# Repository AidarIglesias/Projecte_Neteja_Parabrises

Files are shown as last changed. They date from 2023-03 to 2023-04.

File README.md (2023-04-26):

# Projecte Eines De Disseny  
## Sistema de Neteja-Parabrises D'Un Automobil  
###### David Miravent, Biel Hornas, Aidar Iglesias  

### Objectiu  
Aquest projecte te com a objectiu dissenyar el l'entorn electronic que conforma el sistema de neteja-parabrises d'un automobil.  

El projecte estara dividit en 7 parts:  

1. Diagrama de blocs i components
2. Esquematic i simulacions
3. Placement i routing (layout v1)
4. Pre-entega (layout v2)
5. Entrega final (layout v3)
6. Muntatge i soldadura
7. Test PCB  

----  

### Caracteristiques i epecificacions  
El sistema de neteja-parabrises te com a caracteristica principal, com ja diu el seu nom, netejar la lluna del parabrises. Com que aquest sistema sera part d'un conjunt de ECUs (Electronic Control Unit) d'un automobil, hi ha un serie d'elements que tots ells tindran en comu:  

* Una etapa de regulacio de tensio (es fara servir [L78S05CV])
* Un microcontrolador (es fara servir un [PIC18F2580] de 28 pins) encarregat del control del nostre modul i de la comunicacio amb els altres
* Un bus de programacio i debug del microcontrolador
* Un bus [CAN] que permet la comunicacio sincrona amb els altres moduls
* Un bus [I2C] (o be [SPI]) per a la comunicacio sincrona interna del nostre modul
* Un bus de comunicacio [USART] que permet monitoritzar el sistema des d'un ordinador extern
* Una botonera per permetre la interaccio entre l'usuari i el modul

El sistema ha de complir les seguents **especificacions**:  

* Dos motors amb el seu final de carrera
* Dues bombes de liquid neteja-parabrises
* Sensor digital de pluja
* Calefactor del vidre

----  

### Funcionament  

El sistema al complet estara controlat per el microcontrolador. Per al moviment dels neteja parabrises, es faran servir dos motors, un per davant i un per darrere. Aquests motors estaran controlats per uns drivers, els quals subministren el corrent necessari per activar uns reles que faran girar els motors en un sentit o en l'altre. Quan l'usuari desitgi o quan el sensor de pluja detecti pluja, el microcontrolador enviara el senyal d'activacio dels motors. Tambe s'incloura un sistema de final de carrera, que indicara quan s'ha acabat el trajecte de la escombreta del neteja-parabrises i la fara canviar de sentit.  

El sistema tambe implementa dues bombes de liquid neteja-parabrises, cadascuna d'elles controlada per un driver i un rele. Aquestes s'activaran quan el conductor ho desitgi i funcionaran de la mateixa manera que el neteja-parabrises: mitjançant un motor.  

Hi haura un mode de neteja automatic, accionat per un sensor digital de pluja. Quan es detecti pluja. Aleshores, el neteja-parabrises es posara en funcionament.  

Hi ha quatre opcions a escollir:
* Activar motor neteja-parabrises davanter
* Activar motor neteja-parabrises darrere
* Automatic (El sensor de pluja activa els neteja-parabrises)  

Mes enlla d'aquests 3 modes de funcionament, si aixi ho desitja, l'usuari pot activar les bombes de liquid manualment. Addicionalment, pot fer que les escombretes fagin una sola passada, tambe amb activacio manual.  

----  

### Diagrama de Blocs  

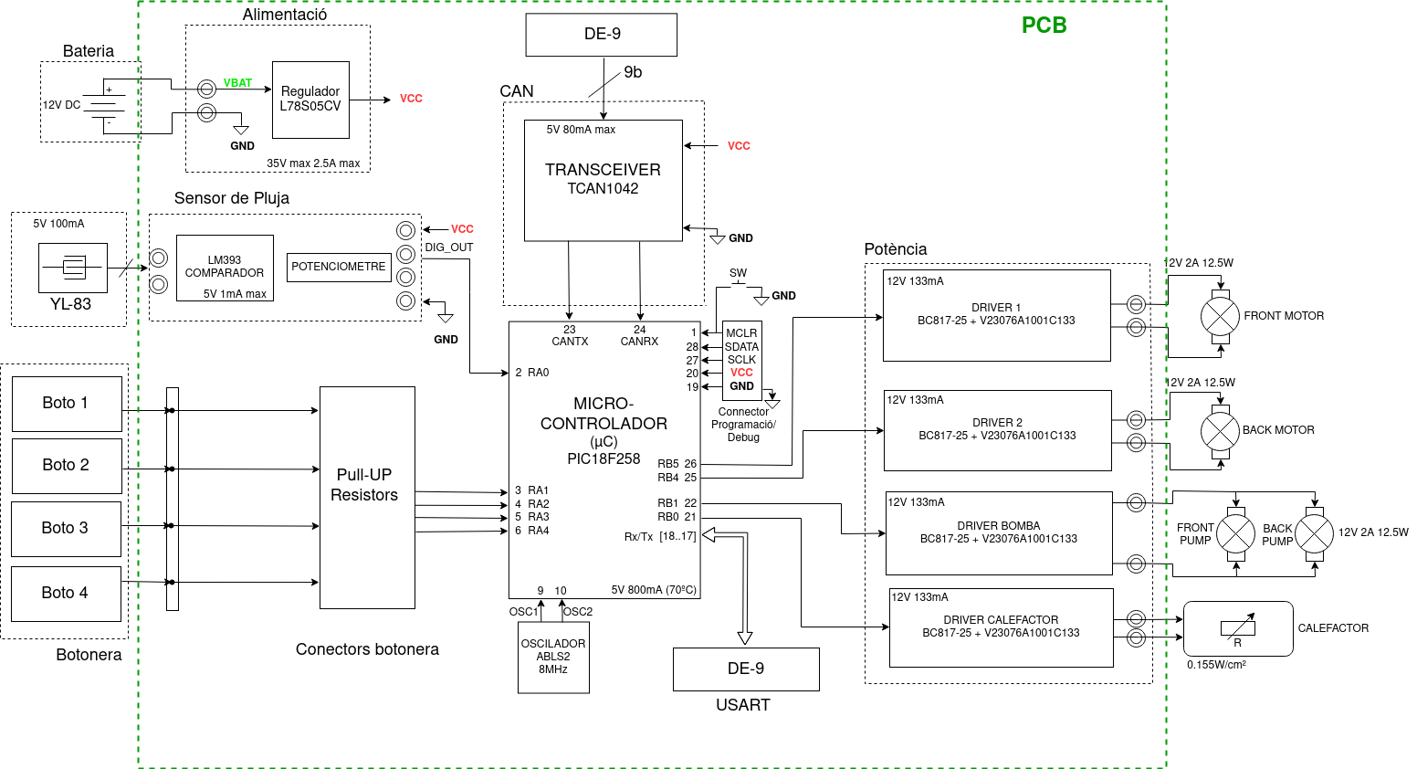
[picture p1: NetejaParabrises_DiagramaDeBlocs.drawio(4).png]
Diagrama 4
  
**Figura 3.** Versio 4 del diagrama de blocs - 13.04.2023.  

----  

### Taula de funcionament dels reles  

| **EnableM1** | **DriverM1** | **MOTOR 1** |  
| --- | --- | --- |
| 0 | 0 | 0 |  
| 0 | 1 | 0 |  
| 1 | 0 | 0 |  
| 1 | 1 | 1 |  

**Taula 1.** Taula del funcionament dels reles del motor neteja-parabrises davanter.  

| **EnableM2** | **DriverM2** | **MOTOR 2** |  
| --- | --- | --- |
| 0 | 0 | 0 |  
| 0 | 1 | 0 |  
| 1 | 0 | 0 |  
| 1 | 1 | 1 |  

**Taula 2.** Taula del funcionament dels reles del motor neteja-parabrises del darrere.

---  

### Components  

| Ref. | Descripcio | Datasheet |  
| ---- | --- | --- |
| PIC18F2580 | 28-Pin High Performance, Enhanced FLASH Microcontroller with CAN. S'encarrega del control integral del sistema. | [PIC18F2580] |  
| TCAN1042 | TCAN1042 Fault Protected CAN Transceiver with CAN FD. L'utilitzarem per a la comunicacio entre moduls independents. | [TCAN1042] |  
| LM1117-5.0 | 2A positive voltage regulator IC. Regulador LDO lineal de tres terminals, corrent nominal 2A i sortida a 5V. | [L78S05CV] |  
| ABLS2-8.000MHZ-D4Y-T | Low Profile Surface Mount Microprocessor Crystal. L'usarem com a font de senyal sincron de referencia per al microcontrolador. Es de 8MHz. | [ABLS2-8MHZ]  
| V23076A1001C133 | Automotive, PCB Single Power Relay K (Sealed) with wide voltage range and limiting continuous current 45A. Utilitzarem aquest rele per a les aplicacions de potencia, com ara la commutacio dels motors, de les bombes i del calefactor. | [V23076A1001C133]  
| BC817-25 | NPN general purpose transistor used for switching and amplification. Features high current (max. 500 mA) and low voltage (max. 45 V). Transistor bipolar NPN que farem servir per a amplificar el corrent de commutacio dels reles. | [BC817-25] |  
| YL-83 | Rain and snow are quickly and accurately detected with the YL-83 Rain Detector. L'implementarem de manera que quan detecti pluja, els neteja-parabrises s'accionin automaticament. | [YL-83] |  
| LM393 | Comparator with lower offset voltage, higher supply voltage capability, lower supply current, lower input bias current, lower propagation delay, and improved 2 kV ESD performance and input ruggedness through dedicated ESD clamps. Comparador que farem servir a l'hora de detectar si plou o no. | [LM393] |  
| 3362-¼” Square Trimpot | Trimming Potentiometer. Withstands harsh environments and immersion cleaning processes. Potenciometre que usarem per adjustar el llindar del sensor de pluja. | [3362-¼” Square Trimpot]  
| Flexible Heaters 78000 Series | Truly transparent, no wires in clear view area, optical grade, thin-film polyester, low power consumption for use with battery or line power. Tires conductores que tenen com a objectiu escalfar la lluna del darrere de l'automobil. | [Flexible Heaters 78000 Series] |  
| WLD4383 | Motor reductor _sinfin_ 12VDC, corrent nominal de 2A, velocitat nominal de 44rmp i una potencia de 12.5W. | [WLD4383]  
| EHDB9MF | Connector DB-9 de entrada-sortida de la comunicacio CAN. | [EHDB9MF] |  

----
### Historial de canvis  

| Data | Autor | Descripcio |  
| ---- | ----- | --- |
| 23.03.2023 | David Miravent | Tramesa de la tasca per a la primera versio de la presentacio. |  
| 27.03.2023 | Biel Hornas, David Miravent, Aidar Iglesias | Diagrama de blocs: Eliminat el sensor de temperatura. Eliminats els busos i transceivers CAN que estaven connectats entre els sensors + els que connectaven el PIC amb els motors. Modificada la botonera. Afegit el nou bus CAN. Modificat el connector de programacio i debug. Modificats els drivers i els components de potencia. Modificat l'oscil·lador. Afegit el driver del sensor de pluja. Afegits els consums individuals de cada component. Inclosos els pins de les connexions PIC-periferics. |  
| 28.03.2023 | Biel Hornas, David Miravent, Aidar Iglesias | Presentacio: Actualitzada la llista de components (diap. 5, 6). Inclosos els parametres d'interes per a cada component (diap. 8 - 18). Actualitzat el diagrama de blocs (diap. 19). |  
| 30.03.2023 | Biel Hornas, David Miravent | Realitzacio simulacions regulador de tensio + sensor de pluja, modificat el esquematic (sch) del projecte : s'han afegit totes les etapes del sistema en estructura de fulles jerarquiques. |  
| 31.03.2023 | Aidar Iglesias | README: actualitzada la imatge del diagrama de blocs. Corregit el valor de consum del PIC. Modificat el connector de la botonera |  
| 04.04.2023 | Biel Hornas | Actualitzada la jerarquia de fulls de l'esquematic: *Alimentacio*, *Digital*, *Analog* i *Potencia*. Sensor de pluja ficat tot en una mateixa capsa. Modificada la botonera: s'han eliminat els interruptors, ja que son externs a la placa. Corregits els noms de les *nets* a l'esquematic dels drivers de motors, que causaven curt-circuits. Canviat el model dels reles a V23086C1001A403, ja que te millor simbol i footprint. Modificat el connector d'alimentacio a l'esquematic del regulador. |  
| 05.04.2023 | David Miravent, Aidar Iglesias | Esquematic: Afegit titol al sheet *root*: **Sistema de Neteja-parabrises**. Modificada la ubicacio del LED d'alimentacio: del PIC al regulador. Reset Manual i Oscil·lador connectats directament al PIC. Corregides les connexions del connector DB-9 del bus CAN. Afegit connector DB-9 per al modul de comunicacio USART. Moduls de comunicacio CAN i USART connectats directament al PIC. |  
| 07.05.2023 | Aidar Iglesias | Esquematic: Canviat el regulador de tensio: LM1117-5 a L78S05CV (corrent de sortida major). Canviats els valors de les capacitats d'entrada i sortida del regulador. Corregides les connexions dels drivers de l'apartat de potencia (feien curt-circuit de la bateria a terra). Diagrama de blocs: actualitzat el regulador de tensio de LM1117 a L78S05CV. Corregits els valors de consum (PIC, LM393, TCAN1042) Presentacio: Actualitzat el diagrama de blocs. |  
| 10.04.2023 | David Miravent, Biel Hornas, Aidar Iglesias | Esquematic: Afegides les ferrites per separar el GND de potencia i el GND general. Layout: dissenyada la primera versio del Layout. |  
| 17.04.2023 | David Miravent, Biel Hornas, Aidar Iglesias | Esquematic: Canviat el node de VBAT al node despres del diode 1n4002 (protegit de canvis de polaritats). Corregida la separacio de GNDPWR i GND al regulador. Canviat el tipus de connector dels motors de pin-header a screwdriver. Canviat el divisor de tensio del sensor de pluja. |  
| 24.04.2023 | Biel Hornas, Aidar Iglesias, David Miravent | Esquematic: afegit el sistema de final de carrera. Assignades les xarxes dels BJTs a la classe ANG. Layout: Canviats totes les capacitats i totes les resistencies a SMD. Dissenyats els copper pours de manera que quedin regulars i uniformes per tota la PCB. Disminuit el tamany de les pistes de potencia. Recolocats alguns components. Re-routing general de la part de potencia. Afegides les llagrimes a les connexions pista-via i pista-pad.  
| 26.04.2023 | David Miravent, Biel Hornas, Aidar Iglesias | Generacio dels fitxers BOM i calcul del pressupost de la placa en tirada curta i llarga. Presentacio: Actualitzades les diapositives de l'esquematic i del layout. |  

[L78S05CV]:(https://www.google.com/url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)
[PIC18F2580]:(https://www.google.com/url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)
[CAN]:(https://www.google.com/url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)  
[I2C]:(https://www.google.com/url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)
[SPI]:(https://www.google.com/url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)
[USART]:(https://www.google.com/url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)
[TCAN1042]:(https://www.ti.com/lit/ds/symlink/tcan1042hv.pdf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)  
[ABLS2-8MHZ]:(https://www.mouser.es/datasheet/2/3/ABLS2-1775116.pdf)  
[V23076A1001C133]:(https://www.farnell.com/datasheets/2243264.pdf)  
[BC817-25]:(https://pdf1.alldatasheet.com/datasheet-pdf/view/16111/PHILIPS/BC817-25.html)  
[YL-83]:(https://urolakostapk.files.wordpress.com/2016/10yl-83-rain-detector-datasheet_low.pdf)  

[LM393]:(https://www.ti.com/lit/ds/symlink/lm393.pdf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)  
[3362-¼” Square Trimpot]:(https://www.farnell.com/datasheets/3171216.pdf)  
[Flexible Heaters 78000 Series]:(https://www.mouser.es/datasheet/2/187/honeywell-sensing-flexible-heaters-line-guide-0090-1525721.pdf)  
[WLD4383]:(https://transmotec.es/product/WLD4383-12-61/)  
[EHDB9MF]:(https://www.switchcraft.com/assets/1/24/EHDB9_EHHD15_SERIES_CD.PDF?4882)

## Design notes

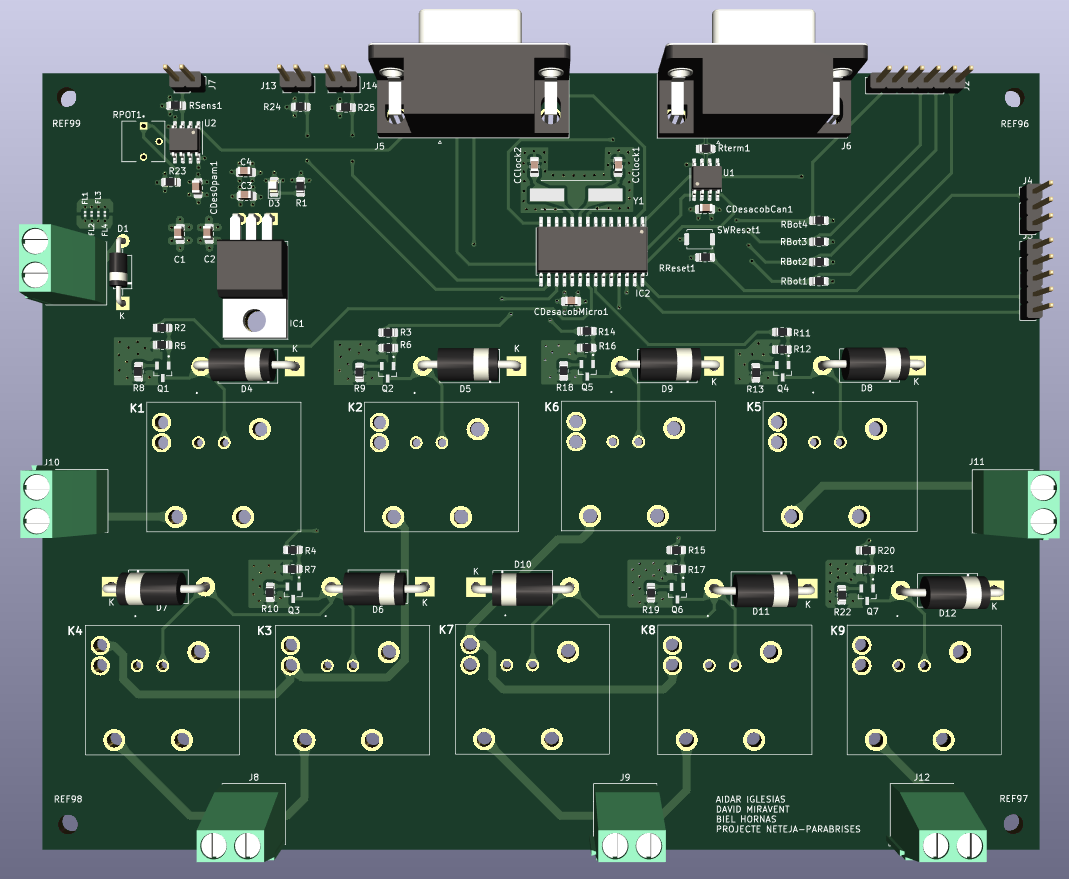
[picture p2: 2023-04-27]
Screenshot from 2023-04-27 13-25-02.png

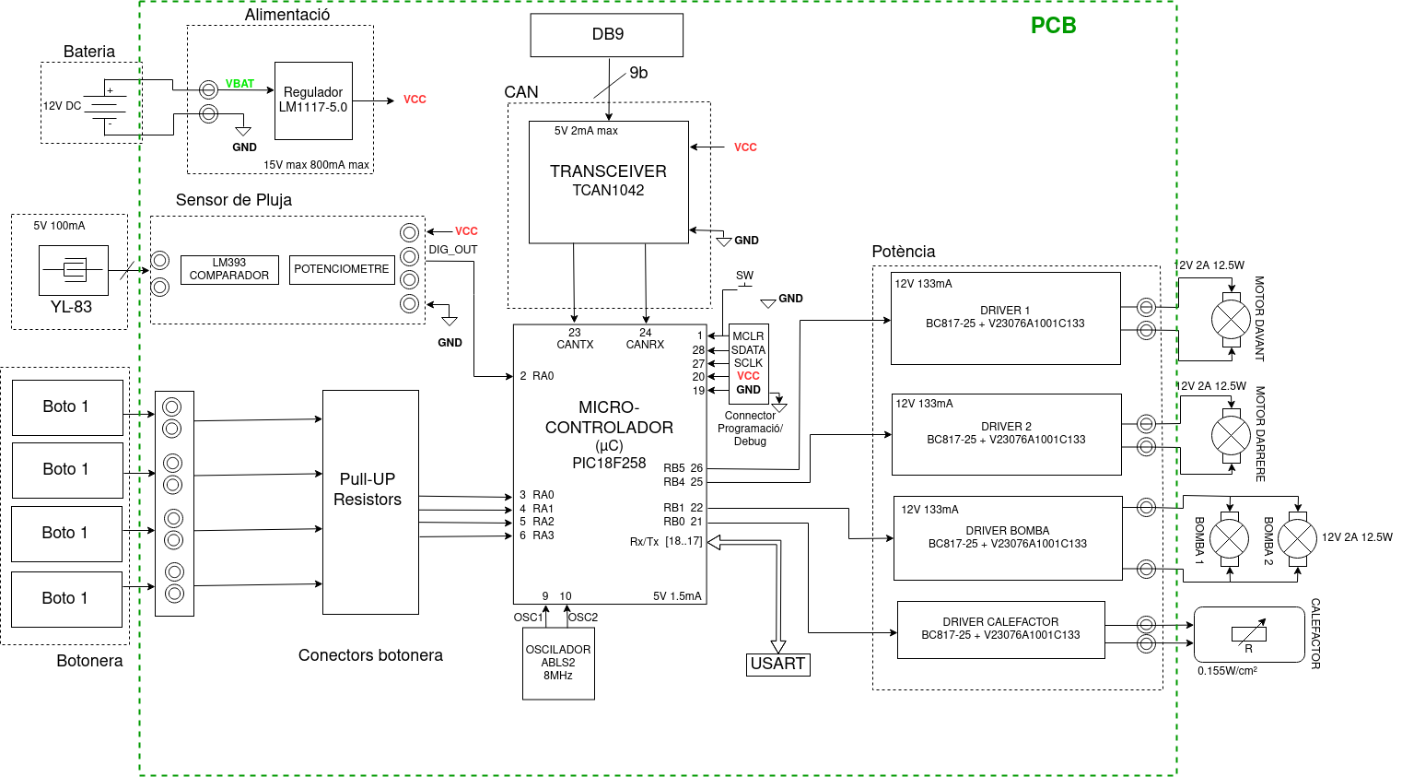
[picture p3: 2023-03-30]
NetejaParabrises_DiagramaDeBlocs.drawio.png

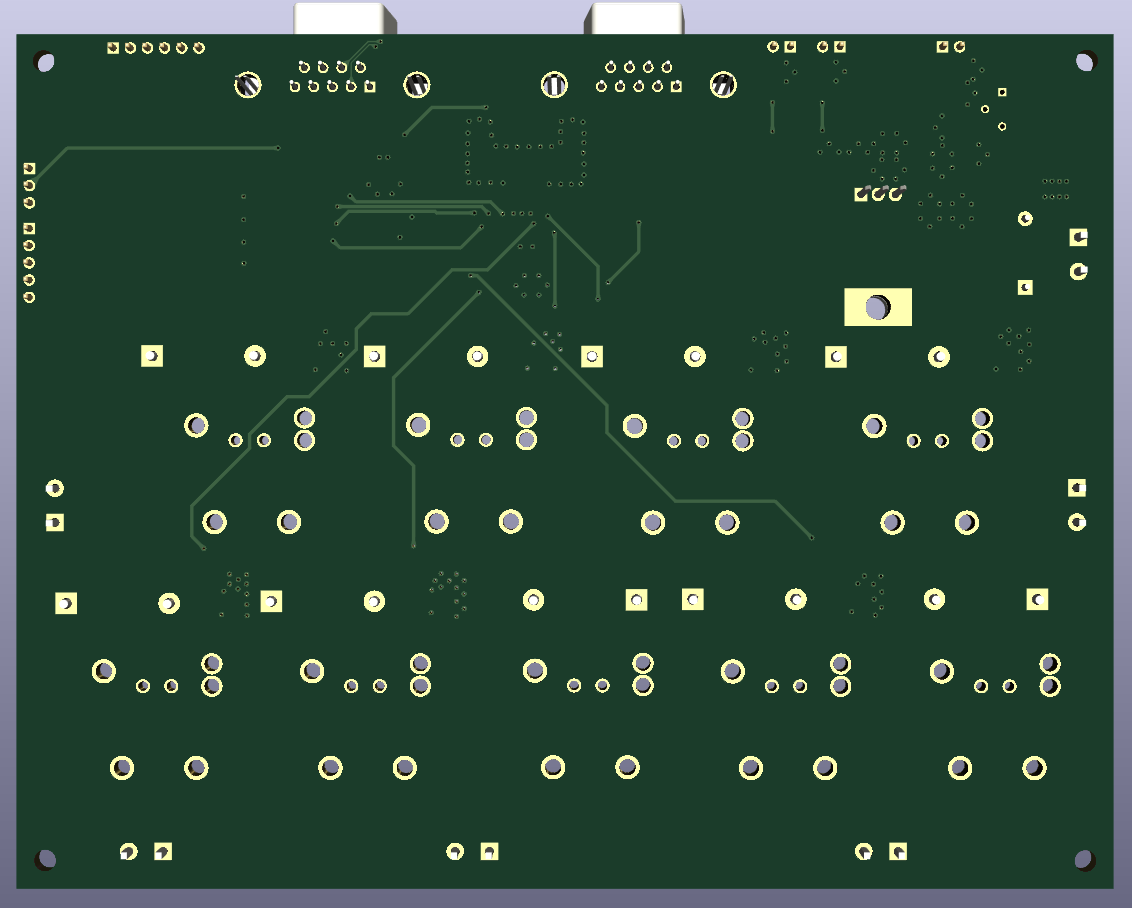
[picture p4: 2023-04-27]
Screenshot from 2023-04-27 13-25-26.png

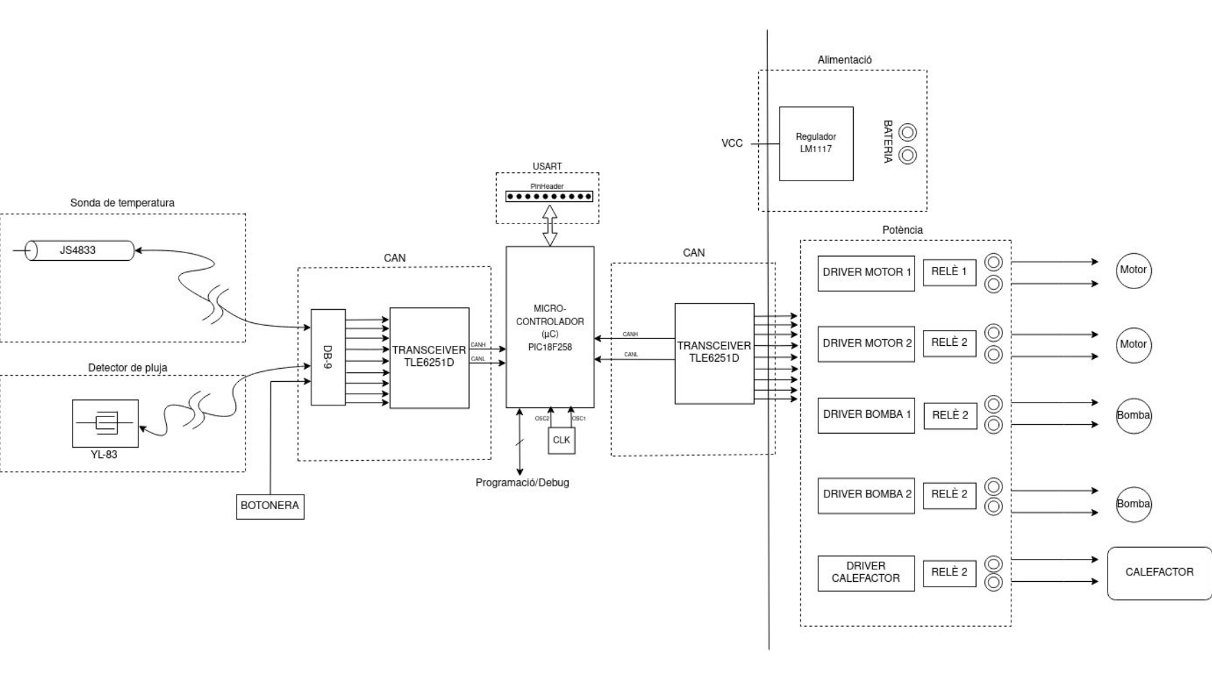
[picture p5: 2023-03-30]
diagrama-de-blocs-v1.png

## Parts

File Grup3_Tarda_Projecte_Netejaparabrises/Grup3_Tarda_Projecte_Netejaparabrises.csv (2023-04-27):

Reference | Value | Footprint | Datasheet | Arrow Part Number | Arrow Price/Stock | CURRENT | Comment | Description | EU_RoHS_Compliance | Height | MANUFACTURER | MAXIMUM_PACKAGE_HEIGHT | Manufacturer_Name | Manufacturer_Part_Number | Mouser Part Number | Mouser Price/Stock | PACKAGE | PARTNUMBER | PARTREV | REFDES | STANDARD | Sim.Device | Sim.Pins | TME | TYPE | VALUE | VIN-MAX | VIN-MIN | VOUT | Qty
C1, C4 | 100n | Capacitor_SMD:C_0805_2012Metric_Pad1.18x1.45mm_HandSolder | ~ |  |  |  |  |  |  |  |  |  |  |  |  |  |  |  |  |  |  |  |  |  |  |  |  |  |  | 2
C2 | 0.33u | Capacitor_SMD:C_0805_2012Metric_Pad1.18x1.45mm_HandSolder | ~ |  |  |  |  |  |  |  |  |  |  |  |  |  |  |  |  |  |  |  |  |  |  |  |  |  |  | 1
C3 | 0.1u | Capacitor_SMD:C_0805_2012Metric_Pad1.18x1.45mm_HandSolder | ~ |  |  |  |  |  |  |  |  |  |  |  |  |  |  |  |  |  |  |  |  |  |  |  |  |  |  | 1
CClock1, CClock2 | 22p | Capacitor_SMD:C_0805_2012Metric_Pad1.18x1.45mm_HandSolder | ~ |  |  |  |  |  |  |  |  |  |  |  |  |  |  |  |  |  |  |  |  |  |  |  |  |  |  | 2
CDesacobCan1 | 100n | Capacitor_SMD:C_0805_2012Metric_Pad1.18x1.45mm_HandSolder | ~ |  |  |  |  |  |  |  |  |  |  |  |  |  |  |  |  |  |  |  |  |  |  |  |  |  |  | 1
CDesacobMicro1 | 100n | Capacitor_SMD:C_0805_2012Metric_Pad1.18x1.45mm_HandSolder | ~ |  |  |  |  |  |  |  |  |  |  |  |  |  |  |  |  |  |  |  |  |  |  |  |  |  |  | 1
CDesOpam1 | 100n | Capacitor_SMD:C_0805_2012Metric_Pad1.18x1.45mm_HandSolder | ~ |  |  |  |  |  |  |  |  |  |  |  |  |  |  |  |  |  |  |  |  |  |  |  |  |  |  | 1
D1 | 1N4002 | Diode_THT:D_DO-41_SOD81_P10.16mm_Horizontal | http://www.vishay.com/docs/88503/1n4001.pdf |  |  |  |  |  |  |  |  |  |  |  |  |  |  |  |  |  |  |  |  |  |  |  |  |  |  | 1
D3 | LED | LED_SMD:LED_0805_2012Metric_Pad1.15x1.40mm_HandSolder | ~ |  |  |  |  |  |  |  |  |  |  |  |  |  |  |  |  |  |  |  |  |  |  |  |  |  |  | 1
D4-D12 | 1N5400 | Diode_THT:D_DO-201AD_P15.24mm_Horizontal | http://www.vishay.com/docs/88516/1n5400.pdf |  |  |  |  |  |  |  |  |  |  |  |  |  |  |  |  |  |  | D | 1=K 2=A |  |  |  |  |  |  | 9
FL1-FL4 | BLM03HD331SZ1D | BLM03HD331SZ1D:BEADC0603X33N |  |  |  |  |  |  |  |  |  |  |  |  |  |  |  |  |  |  |  |  |  |  |  |  |  |  |  | 4
IC1 | L78S05CV | Libreia:TO-220-3_Horizontal_TabDown_mod |  |  |  | 2.0 A |  |  |  |  | St Microelectronics |  |  |  |  |  | TO-220 |  |  |  |  |  |  | L78S05CV |  |  | 35.0 V | 8.0 V | 5.0 V | 1
IC2 | PIC18F258-I_SO | Package_SO:SOIC-28W_7.5x17.9mm_P1.27mm | https://datasheet.datasheetarchive.com/originals/distributors/Datasheets-35/DSA-681538.pdf | PIC18F258-I/SO | https://www.arrow.com/en/products/pic18f258-iso/microchip-technology |  |  | Microcontroller,PIC18F258-I/SO 40MHz |  | 2.64 |  |  | Microchip | PIC18F258-I/SO | 579-PIC18F258-I/SO | https://www.mouser.co.uk/ProductDetail/Microchip-Technology-Atmel/PIC18F258-I-SO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 |  |  |  |  |  |  |  |  |  |  |  |  |  | 1
J1, J8-J12 | Screw_Terminal_01x02 | TerminalBlock_Phoenix:TerminalBlock_Phoenix_MKDS-1,5-2-5.08_1x02_P5.08mm_Horizontal | ~ |  |  |  |  |  |  |  |  |  |  |  |  |  |  |  |  |  |  |  |  |  |  |  |  |  |  | 6
J2 | BOTONERA | Connector_PinHeader_2.54mm:PinHeader_1x06_P2.54mm_Vertical | ~ |  |  |  |  |  |  |  |  |  |  |  |  |  |  |  |  |  |  |  |  |  |  |  |  |  |  | 1
J3 | PROGRAMMING CON | Connector_PinHeader_2.54mm:PinHeader_1x05_P2.54mm_Vertical | ~ |  |  |  |  |  |  |  |  |  |  |  |  |  |  |  |  |  |  |  |  |  |  |  |  |  |  | 1
J4 | JP1 | Connector_PinHeader_2.54mm:PinHeader_1x03_P2.54mm_Vertical | ~ |  |  |  |  |  |  |  |  |  |  |  |  |  |  |  |  |  |  |  |  |  |  |  |  |  |  | 1
J5, J6 | DE9_Plug_MountingHoles | Connector_Dsub:DSUB-9_Female_Horizontal_P2.77x2.84mm_EdgePinOffset4.94mm_Housed_MountingHolesOffset7.48mm | ~ |  |  |  |  |  |  |  |  |  |  |  |  |  |  |  |  |  |  |  |  |  |  |  |  |  |  | 2
J7 | CONEXIOSENSOR | Connector_PinHeader_2.54mm:PinHeader_1x02_P2.54mm_Vertical | ~ |  |  |  |  |  |  |  |  |  |  |  |  |  |  |  |  |  |  |  |  |  |  |  |  |  |  | 1
J13, J14 | FINAL DE CARRERA | Connector_PinHeader_2.54mm:PinHeader_1x02_P2.54mm_Vertical | ~ |  |  |  |  |  |  |  |  |  |  |  |  |  |  |  |  |  |  |  |  |  |  |  |  |  |  | 2
K1-K9 | 1393280-6 | V23076A1001C133:V23076A1001C133 |  |  |  |  | 1393280-6 |  | Compliant |  |  |  |  |  |  |  |  |  |  |  |  |  |  |  |  |  |  |  |  | 9
Q1-Q7 | BC817-25_RF | BC817-25_RF:SOT95P237X112-3N |  |  |  |  |  |  |  |  | Taiwan Semiconductor | 1.12mm |  |  |  |  |  |  | I2001 |  | IPC 7351B |  |  |  |  |  |  |  |  | 7
R1 | 220R | Resistor_SMD:R_0805_2012Metric_Pad1.20x1.40mm_HandSolder | ~ |  |  |  |  |  |  |  |  |  |  |  |  |  |  |  |  |  |  |  |  |  |  |  |  |  |  | 1
R2-R4, R11, R14, R15, R20 | 620.3R | Resistor_SMD:R_0805_2012Metric_Pad1.20x1.40mm_HandSolder | ~ |  |  |  |  |  |  |  |  |  |  |  |  |  |  |  |  |  |  |  |  |  |  |  |  |  |  | 7
R5-R7, R12, R16, R17, R21 | 319.6R | Resistor_SMD:R_0805_2012Metric_Pad1.20x1.40mm_HandSolder | ~ |  |  |  |  |  |  |  |  |  |  |  |  |  |  |  |  |  |  |  |  |  |  |  |  |  |  | 7
R8-R10, R13, R18, R19, R22 | 13.4R | Resistor_SMD:R_0805_2012Metric_Pad1.20x1.40mm_HandSolder | ~ |  |  |  |  |  |  |  |  |  |  |  |  |  |  |  |  |  |  |  |  |  |  |  |  |  |  | 7
R23 | 10k | Resistor_SMD:R_0805_2012Metric_Pad1.20x1.40mm_HandSolder | ~ |  |  |  |  |  |  |  |  |  |  |  |  |  |  |  |  |  |  |  |  |  |  |  |  |  |  | 1
R24, R25 | 22k | Resistor_SMD:R_0805_2012Metric_Pad1.20x1.40mm_HandSolder | ~ |  |  |  |  |  |  |  |  |  |  |  |  |  |  |  |  |  |  |  |  |  |  |  |  |  |  | 2
RBot1-RBot4 | 22k | Resistor_SMD:R_0805_2012Metric_Pad1.20x1.40mm_HandSolder | ~ |  |  |  |  |  |  |  |  |  |  |  |  |  |  |  |  |  |  |  |  |  |  |  |  |  |  | 4
RPOT1 | 10k | POTENCIOMETRE:TRIM_3362P-1-103 | ~ |  |  |  |  |  |  |  |  |  |  |  |  |  |  |  |  |  |  |  |  |  |  |  |  |  |  | 1
RReset1 | 4.7k | Resistor_SMD:R_0805_2012Metric_Pad1.20x1.40mm_HandSolder | ~ |  |  |  |  |  |  |  |  |  |  |  |  |  |  |  |  |  |  |  |  |  |  |  |  |  |  | 1
RSens1 | 1k | Resistor_SMD:R_0805_2012Metric_Pad1.20x1.40mm_HandSolder | ~ |  |  |  |  |  |  |  |  |  |  |  |  |  |  |  |  |  |  |  |  |  |  |  |  |  |  | 1
Rterm1 | 120R | Resistor_SMD:R_0805_2012Metric_Pad1.20x1.40mm_HandSolder | ~ |  |  |  |  |  |  |  |  |  |  |  |  |  |  |  |  |  |  |  |  |  |  |  |  |  |  | 1
SWReset1 | SW_Push | Button_Switch_SMD:SW_Push_SPST_NO_Alps_SKRK | ~ |  |  |  |  |  |  |  |  |  |  |  |  |  |  |  |  |  |  |  |  |  |  |  |  |  |  | 1
U1 | TCAN1042DRQ1 | Package_SO:SOIC-8_3.9x4.9mm_P1.27mm |  |  |  |  |  |  |  |  | Texas Instruments |  |  |  |  |  |  | TCAN1042DRQ1 |  | RefDes |  |  |  |  | TYPE | Value |  |  |  | 1
U2 | LM393 | Package_SO:SOIC-8_3.9x4.9mm_P1.27mm | http://www.ti.com/lit/ds/symlink/lm393.pdf |  |  |  |  |  |  |  |  |  |  |  |  |  |  |  |  |  |  |  |  |  |  |  |  |  |  | 1
Y1 | ABLS2-8.000MHZ-D4Y-T | XTAL_ABLS2-8:XTAL_ABLS2-8.000MHZ-D4Y-T |  |  |  |  |  |  |  |  | Abracon | 3.3 mm |  |  |  |  |  |  | 11.15.2016 |  | Manufacturer Recommendations |  |  |  |  |  |  |  |  | 1

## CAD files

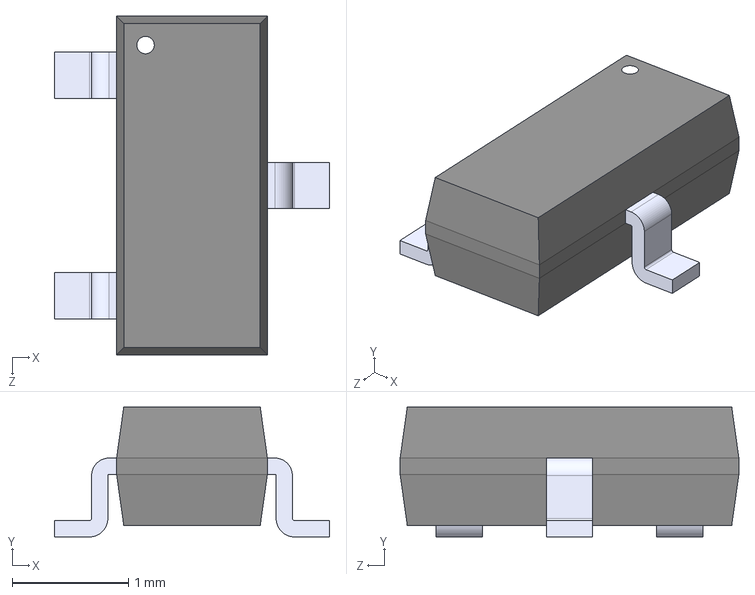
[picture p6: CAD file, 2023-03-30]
Llibreries/BJT/BC817-25_RF.step
2.37 x 1.12 x 2.92 mm

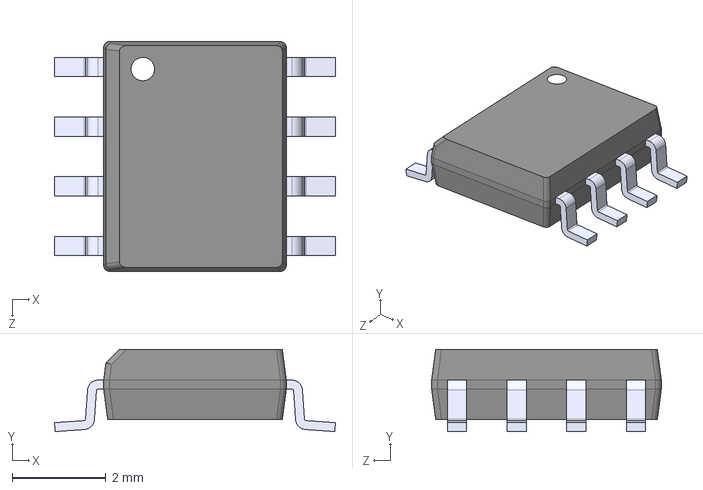
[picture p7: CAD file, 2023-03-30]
Llibreries/Comparador/LM393D.step
5.99 x 1.75 x 4.90 mm

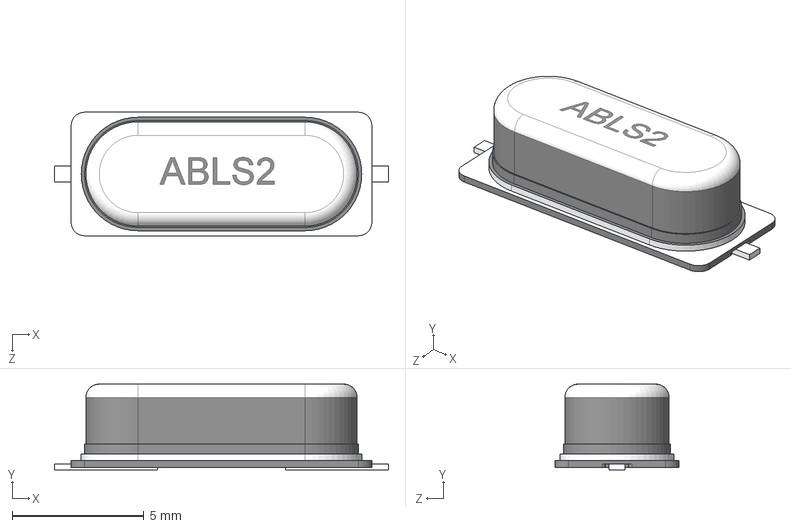
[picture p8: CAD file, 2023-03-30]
Llibreries/Cristall/ABLS2-8.000MHZ-D4Y-T.step
12.7 x 3.27 x 4.70 mm

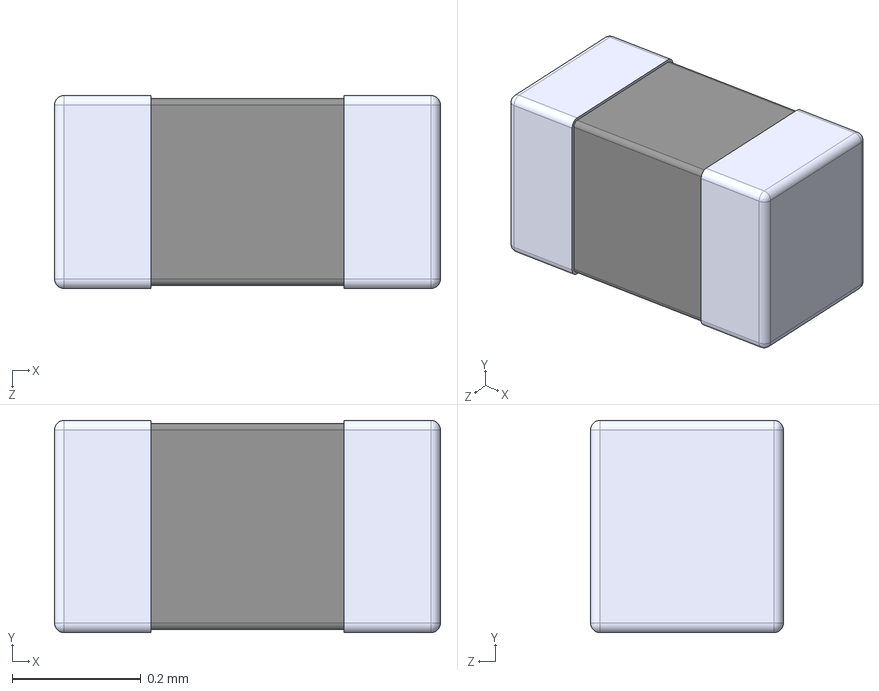
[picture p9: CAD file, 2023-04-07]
Llibreries/Ferritas/BLM03HD331SZ1D.step
0.6 x 0.33 x 0.3 mm

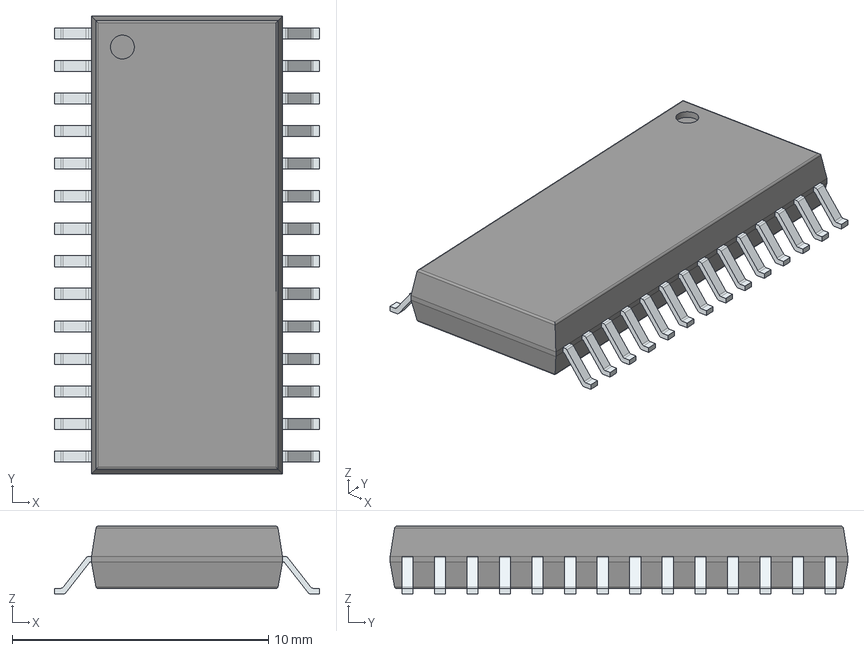
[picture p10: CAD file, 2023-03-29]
Llibreries/Micro/LIB_PIC18F258-I_SO/PIC18F258-I_SO/3D/PIC18F258-I_SO.stp
10.3 x 17.9 x 2.64 mm
PinsArrayLR

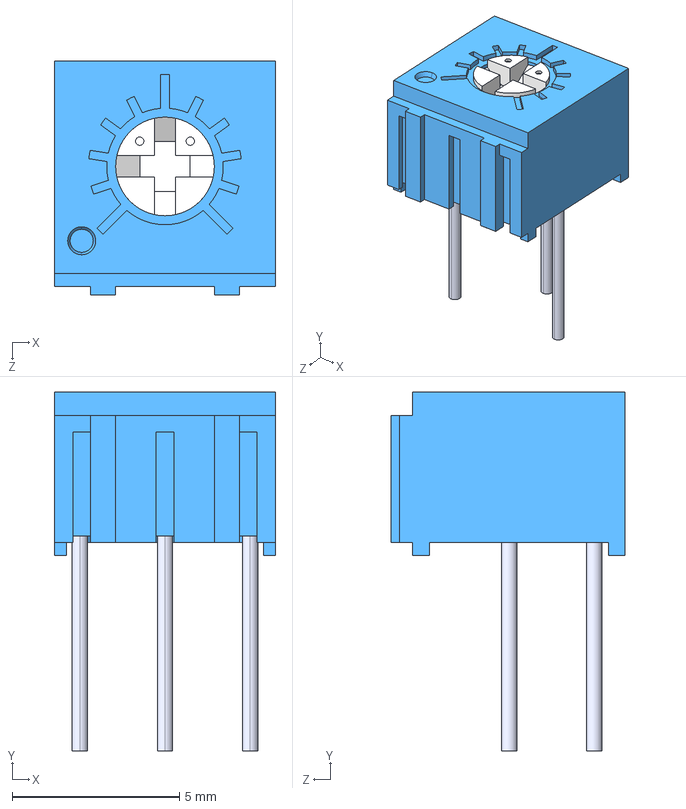
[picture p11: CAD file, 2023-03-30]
Llibreries/Potenciometre/3362P-1-103.step
6.60 x 10.7 x 6.99 mm

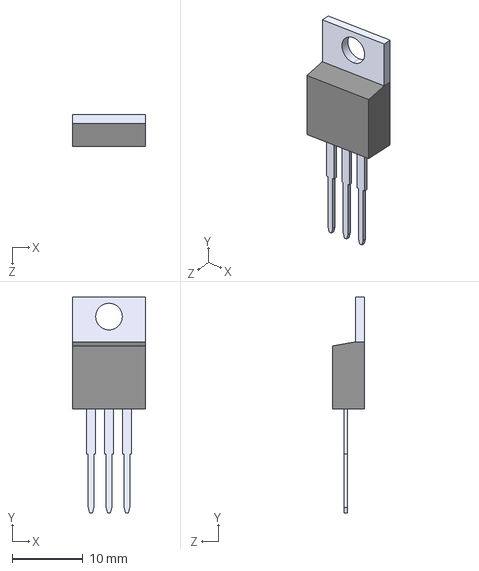
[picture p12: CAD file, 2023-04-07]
Llibreries/Regulador/L78S05CV.step
10.3 x 30.6 x 4.57 mm

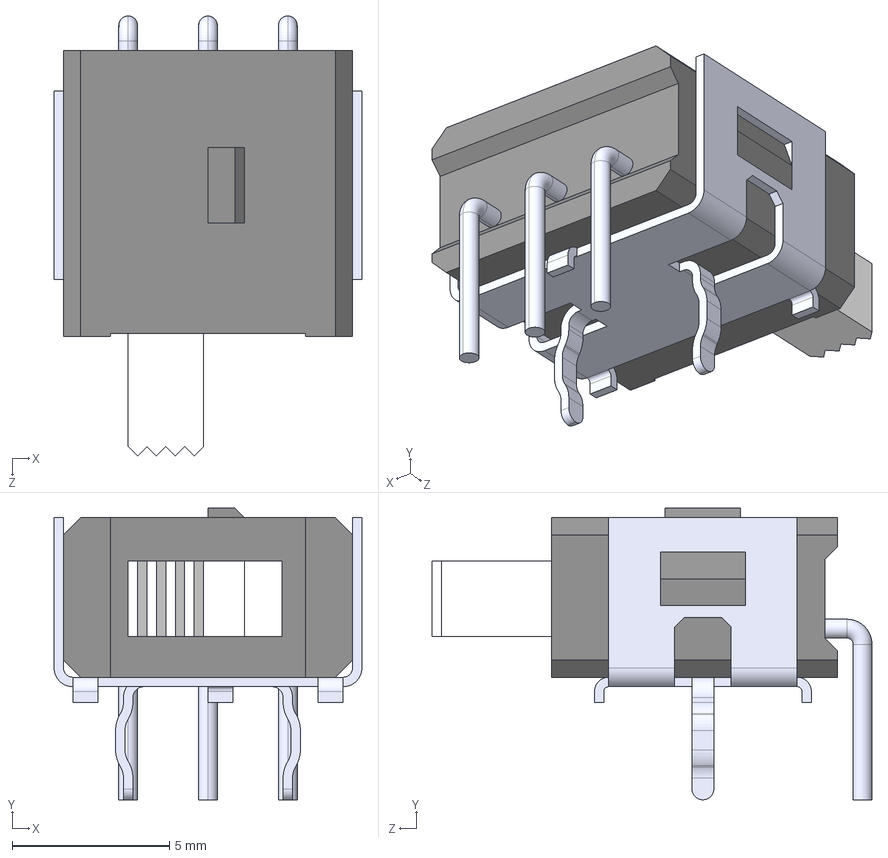
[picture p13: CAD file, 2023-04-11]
Llibreries/switch1x1/AS11CH/AS11CH.step
9.80 x 9.28 x 14.0 mm

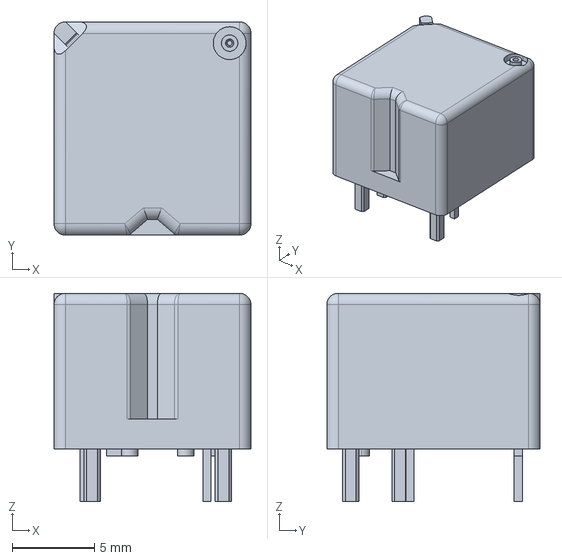
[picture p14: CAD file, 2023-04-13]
Llibreries/Rele/1393280-6/1393280-6.step
12.0 x 13.0 x 12.7 mm

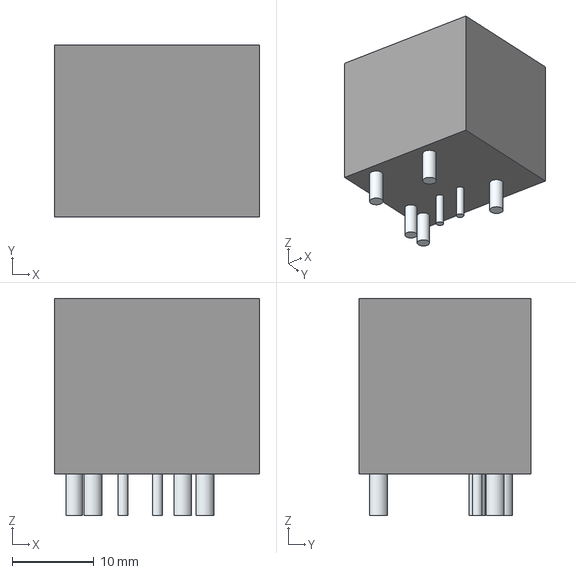
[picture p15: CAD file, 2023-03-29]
Llibreries/Rele/LIB_V23076A1001C133/V23076A1001C133/3D/V23076A1001C133.stp
25.1 x 21.1 x 26.6 mm
Leads x 7

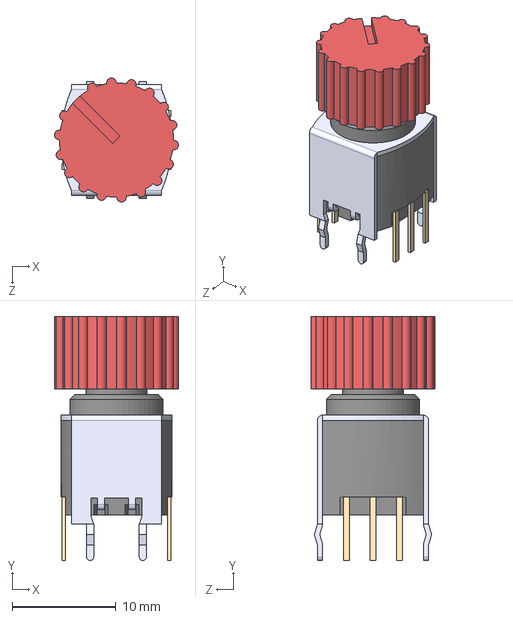
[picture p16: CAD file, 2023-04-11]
Llibreries/switch3x1/NR01103ANG13-1C/NR01103ANG13-1C.step
12.0 x 23.5 x 12.0 mm

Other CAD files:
Llibreries/Micro/LIB_PIC18F258-I_SO/PIC18F258-I_SO/Allegro/soic127p1034x264-28n.psm
Llibreries/Micro/LIB_PIC18F258-I_SO/PIC18F258-I_SO/DEHDL/pic18f258_i_so/chips/chips.prt
Llibreries/Rele/LIB_V23076A1001C133/V23076A1001C133/Allegro/v23076a1001c133.psm
Llibreries/Rele/LIB_V23076A1001C133/V23076A1001C133/DEHDL/v23076a1001c133/chips/chips.prt

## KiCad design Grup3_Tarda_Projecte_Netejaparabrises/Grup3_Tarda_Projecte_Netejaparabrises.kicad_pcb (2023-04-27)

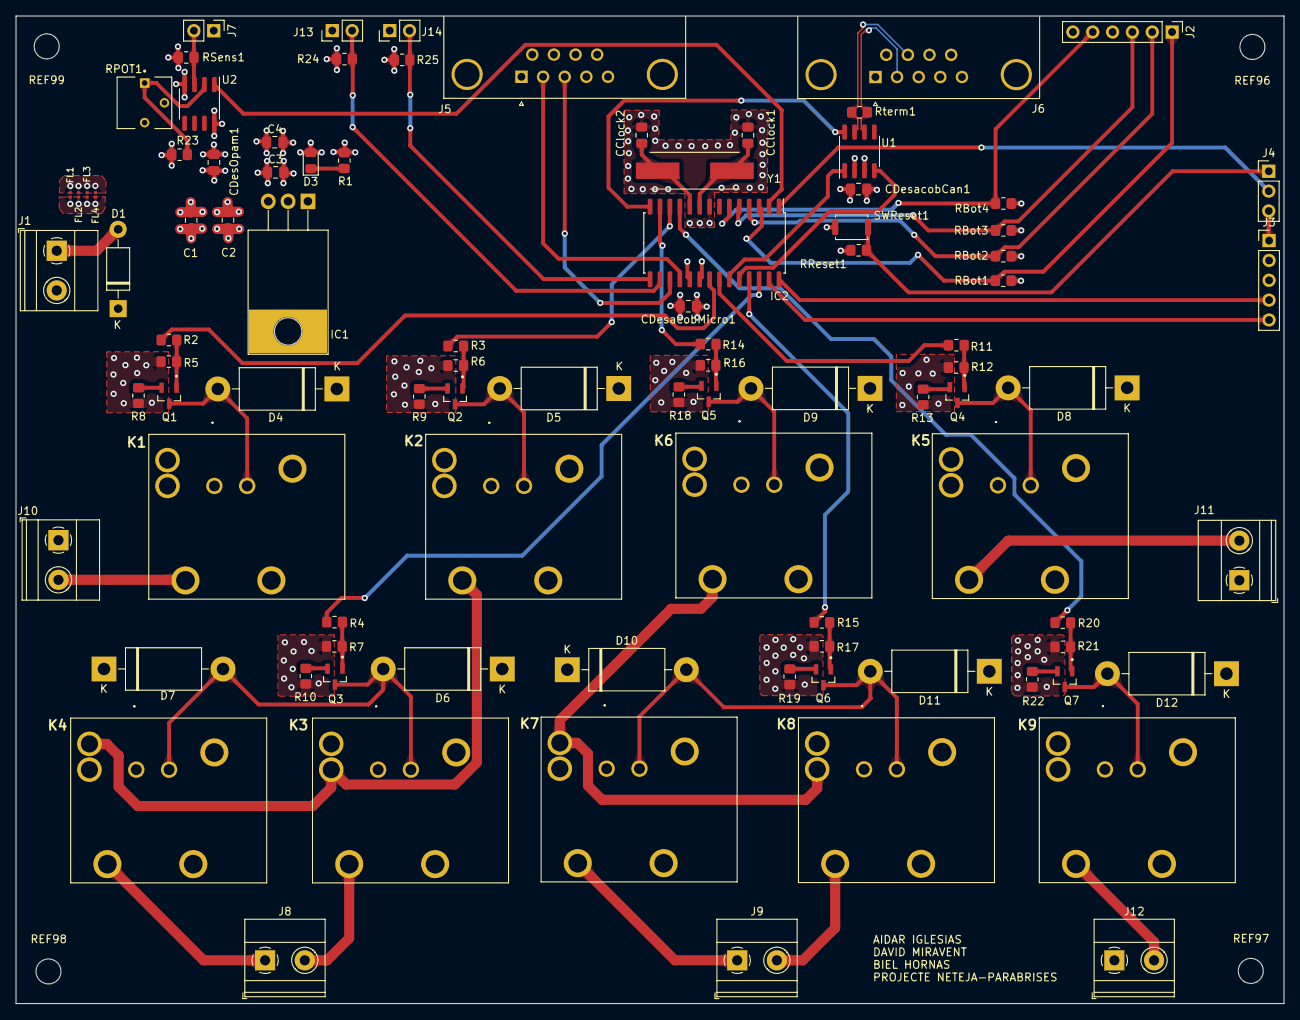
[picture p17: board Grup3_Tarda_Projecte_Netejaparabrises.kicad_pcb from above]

Board: 4 copper layers, 162.4 x 126.5 mm, 97 parts (0 on the bottom side), 66 nets.

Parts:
C1, C4: 100n; C_0805_2012Metric_Pad1.18x1.45mm_HandSolder
C2: 0.33u; C_0805_2012Metric_Pad1.18x1.45mm_HandSolder
C3: 0.1u; C_0805_2012Metric_Pad1.18x1.45mm_HandSolder
CClock1, CClock2: 22p; C_0805_2012Metric_Pad1.18x1.45mm_HandSolder
CDesOpam1: 100n; C_0805_2012Metric_Pad1.18x1.45mm_HandSolder
CDesacobCan1: 100n; C_0805_2012Metric_Pad1.18x1.45mm_HandSolder
CDesacobMicro1: 100n; C_0805_2012Metric_Pad1.18x1.45mm_HandSolder
D1: 1N4002; D_DO-41_SOD81_P10.16mm_Horizontal
D3: LED; LED_0805_2012Metric_Pad1.15x1.40mm_HandSolder
D4, D5, D6, D7, D8, D9, D10, D11, D12: 1N5400; D_DO-201AD_P15.24mm_Horizontal
FL1, FL2, FL3, FL4: BLM03HD331SZ1D; BEADC0603X33N
IC1: L78S05CV; TO-220-3_Horizontal_TabDown_mod
IC2: PIC18F258-I_SO; SOIC-28W_7.5x17.9mm_P1.27mm
J1, J8, J9, J10, J11, J12: Screw_Terminal_01x02; TerminalBlock_Phoenix_MKDS-1,5-2-5.08_1x02_P5.08mm_Horizont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
J2: BOTONERA; PinHeader_1x06_P2.54mm_Vertical
J3: PROGRAMMING CON; PinHeader_1x05_P2.54mm_Vertical
J4: JP1; PinHeader_1x03_P2.54mm_Vertical
J5, J6: DE9_Plug_MountingHoles; DSUB-9_Female_Horizontal_P2.77x2.84mm_EdgePinOffset4.94mm_H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
J7: CONEXIOSENSOR; PinHeader_1x02_P2.54mm_Vertical
J13, J14: FINAL DE CARRERA; PinHeader_1x02_P2.54mm_Vertical
K1, K2, K3, K4, K5, K6, K7, K8, K9: 1393280-6; V23076A1001C133
Q1, Q2, Q3, Q4, Q5, Q6, Q7: BC817-25_RF; SOT95P237X112-3N
R1: 220R; R_0805_2012Metric_Pad1.20x1.40mm_HandSolder
R2, R3, R4, R11, R14, R15, R20: 620.3R; R_0805_2012Metric_Pad1.20x1.40mm_HandSolder
R5, R6, R7, R12, R16, R17, R21: 319.6R; R_0805_2012Metric_Pad1.20x1.40mm_HandSolder
R8, R9, R10, R13, R18, R19, R22: 13.4R; R_0805_2012Metric_Pad1.20x1.40mm_HandSolder
R23: 10k; R_0805_2012Metric_Pad1.20x1.40mm_HandSolder
R24, R25: 22k; R_0805_2012Metric_Pad1.20x1.40mm_HandSolder
RBot1, RBot2, RBot3, RBot4: 22k; R_0805_2012Metric_Pad1.20x1.40mm_HandSolder
REF96, REF97, REF98, REF99: MountingHole_3.2mm_M3_ISO7380
RPOT1: 10k; TRIM_3362P-1-103
RReset1: 4.7k; R_0805_2012Metric_Pad1.20x1.40mm_HandSolder
RSens1: 1k; R_0805_2012Metric_Pad1.20x1.40mm_HandSolder
Rterm1: 120R; R_0805_2012Metric_Pad1.20x1.40mm_HandSolder
SWReset1: SW_Push; SW_Push_SPST_NO_Alps_SKRK
U1: Value; SOIC-8_3.9x4.9mm_P1.27mm
U2: LM393; SOIC-8_3.9x4.9mm_P1.27mm
Y1: ABLS2-8.000MHZ-D4Y-T; XTAL_ABLS2-8.000MHZ-D4Y-T

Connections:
+VCC: C3.1, C4.1, CDesOpam1.1, CDesacobCan1.1, CDesacobMicro1.1, D3.2 (A), IC1.3, IC2.20 (VDD), J3.2, J7.1, R23.1, R24.1, R25.1, RBot1.1, RBot2.1, RBot3.1, RBot4.1, RReset1.1, U1.3 (VCC), U2.8 (V+)
/Alimentacio/Vbat: D1.2 (A), J1.1
/Alimentacio/Vled: D3.1 (K), R1.1
/Analog/Vsensibilitat: R23.2, RPOT1.1, U2.2 (-)
/Analog/Vsensor: J7.2, RSens1.1, U2.3 (+)
/Digital/CAN+: J6.2, Rterm1.1, U1.6 (CANL)
/Digital/CAN-: J6.7, Rterm1.2, U1.7 (CANH)
/Digital/CANRX: IC2.24 (RB3/CANRX), U1.4 (RXD)
/Digital/CANTX: IC2.23 (RB2/CANTX/INT2), U1.1 (TXD)
/Digital/MCLR: IC2.1 (~MCLR/VPP), J4.2
/Digital/PROG_MCLR: J3.1, J4.3
/Digital/Rx: IC2.18 (RC7/RX/DT), J5.2
/Digital/Tx: IC2.17 (RC6/TX/CK), J5.3
/Digital/Vboto1: IC2.3 (RA1/AN1), J2.1, RBot1.2
/Digital/Vboto2: IC2.4 (RA2/AN2/VREF-), J2.2, RBot2.2
/Digital/Vboto3: IC2.5 (RA3/AN3/VREF+), J2.3, RBot3.2
/Digital/Vboto4: IC2.6 (RA4/T0CKI), J2.5, RBot4.2
/Digital/Vfin_back: IC2.15 (RC4/SDI/SDA), J14.2, R25.2
/Digital/Vfin_front: IC2.16 (RC5/SDO), J13.2, R24.2
/Digital/Vsw: J4.1, RReset1.2, SWReset1.1
/Digital/XTAL1: CClock1.1, IC2.9 (OSC1/CLKI), Y1.1
/Digital/XTAL2: CClock2.1, IC2.10 (OSC2/CLKO/RA6), Y1.2
/Potencia/Vb_EN1: Q2.1, R3.2, R6.2
/Potencia/Vb_EN2: Q5.1, R14.2, R16.2
/Potencia/Vb_b1: Q1.1, R2.2, R5.2
/Potencia/Vb_b2: Q4.1, R11.2, R12.2
/Potencia/Vb_lu: Q7.1, R20.2, R21.2
/Potencia/Vb_m1: Q3.1, R4.2, R7.2
/Potencia/Vb_m2: Q6.1, R15.2, R17.2
/Potencia/Vc_EN1: D5.2 (A), K2.2, Q2.3
/Potencia/Vc_EN2: D9.2 (A), K6.2, Q5.3
/Potencia/Vc_b1: D4.2 (A), K1.2, Q1.3
/Potencia/Vc_b2: D8.2 (A), K5.2, Q4.3
/Potencia/Vc_lu: D12.2 (A), K9.2, Q7.3
/Potencia/Vc_m1: D6.2 (A), D7.2 (A), K3.2, K4.2, Q3.3
/Potencia/Vc_m2: D10.2 (A), D11.2 (A), K7.2, K8.2, Q6.3
/Potencia/Ve_EN1: Q2.2, R9.2
/Potencia/Ve_EN2: Q5.2, R18.2
/Potencia/Ve_b1: Q1.2, R8.2
/Potencia/Ve_b2: Q4.2, R13.2
/Potencia/Ve_lu: Q7.2, R22.2
/Potencia/Ve_m1: Q3.2, R10.2
/Potencia/Ve_m2: Q6.2, R19.2
DriverB1: IC2.21 (RB0/INT0), R2.1
DriverB2: IC2.22 (RB1/INT1), R11.1
DriverLuneta: IC2.11 (RC0/T1OSO/T1CKI), R20.1
DriverM1: IC2.26 (RB5/PGM), R4.1
DriverM2: IC2.25 (RB4), R15.1
EN1: K2.4, K3.5, K4.3
EN2: K6.4, K7.3, K8.5
EnableM1: IC2.12 (RC1/T1OSI), R3.1
EnableM2: IC2.13 (RC2/CCP1), R14.1
GND: C3.2, C4.2, CClock1.2, CClock2.2, CDesOpam1.2, CDesacobCan1.2, CDesacobMicro1.2, FL1.2, FL2.2, FL3.2, FL4.2, IC2.8 (VSS_1), IC2.19 (VSS_2), J2.4, J2.6, J3.3, J5.5, J6.6, J13.1, J14.1, R1.2, RPOT1.2, RPOT1.3, RSens1.2, SWReset1.2, U1.2 (GND), U2.4 (V-)
GNDPWR: C1.2, C2.2, FL1.1, FL2.1, FL3.1, FL4.1, IC1.2, J1.2, J10.1, J11.1, J12.1, K1.3, K2.3, K3.3, K4.5, K5.3, K6.3, K7.5, K8.3, K9.3, R5.1, R6.1, R7.1, R8.1, R9.1, R10.1, R12.1, R13.1, R16.1, R17.1, R18.1, R19.1, R21.1, R22.1
PGC: IC2.27 (RB6/PGC), J3.5
PGD: IC2.28 (RB7/PGD), J3.4
STB: IC2.14 (RC3/SCK/SCL), U1.8 (STB)
Sensordig_o: IC2.2 (RA0/AN0/CVREF), U2.1
VBAT: C1.1, C2.1, D1.1 (K), D4.1 (K), D5.1 (K), D6.1 (K), D7.1 (K), D8.1 (K), D9.1 (K), D10.1 (K), D11.1 (K), D12.1 (K), IC1.1, K1.1, K1.5, K2.1, K2.5, K3.1, K4.1, K5.1, K5.5, K6.1, K6.5, K7.1, K8.1, K9.1, K9.5
VBOMBA1: J10.2, K1.4
VBOMBA2: J11.2, K5.4
VLUNETA: J12.2, K9.4
VMOT1+: J8.2, K3.4
VMOT1-: J8.1, K4.4
VMOT2+: J9.2, K8.4
VMOT2-: J9.1, K7.4

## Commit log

2023-03-28 canvi de nom del README
2023-03-30 canvis llibreries i requeriments
    [3362P-1-103.step, ABLS2-8.000MHZ-D4Y-T--3DModel-STEP-400430.STEP, ABLS2-8.000MHZ-D4Y-T.step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]
2023-03-30 canvis llibreries i projecte
    [ABLS2-8.000MHZ-D4Y-T--3DModel-STEP-400430.STEP, ABLS2-8.000MHZ-D4Y-T.step, BC817-25.STEP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]
2023-03-30 canvis esquematic
    [Alimentacio.kicad_sch, Botonera.kicad_sch, Comunicacions.kicad_sch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]
2023-04-03 Modificat nets dels drivers de motors bombes... botonera i sensor de pluja millorats i amb connectors
    [Botonera.kicad_sch, Potencia.kicad_sch, Sensor_Pluja.kicad_sch]
2023-04-05 Canvis estructura general, reles, comunicacacions i clock
    [Sensor_Pluja.kicad_sch]
2023-04-05 canvis schematic 05-04-23
    [Alimentacio.kicad_sch, Grup3_Tarda_Projecte_Netejaparabrises.kicad_sch, Microcontrolador.kicad_sch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]
2023-04-07 canvis schematic i README 07-04-2023
    [Alimentacio.kicad_sch, Grup3_Tarda_Projecte_Netejaparabrises.kicad_sch, L78S05CV.step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]
2023-04-07 canvis reles 07-04-2023
    [Alimentacio.kicad_sch, BLM03HD331SZ1D.step, Microcontrolador.kicad_sch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]
2023-04-08 GNDS 08042023
    [Alimentacio.kicad_sch, Grup3_Tarda_Projecte_Netejaparabrises.kicad_pcb, Microcontrolador.kicad_sch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]
2023-04-10 Layout Esquema
    [Alimentacio.kicad_sch, Grup3_Tarda_Projecte_Netejaparabrises.kicad_pcb, Microcontrolador.kicad_sch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]
2023-04-11 esborrats sheets vells
    [Botonera.kicad_sch, Comunicacions.kicad_sch]
2023-04-11 Modificacions finals assignacio footprints
    [AS11CH.step, Alimentacio.kicad_sch, Botonera.kicad_sch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]
2023-04-11 Sense errors de visualització, preparat pel layout
    [Alimentacio.kicad_sch, Microcontrolador.kicad_sch, Potencia.kicad_sch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]
2023-04-11 canvis menors a esquematic i README
    [Grup3_Tarda_Projecte_Netejaparabrises.kicad_sch, Microcontrolador.kicad_sch, Potencia.kicad_sch]
2023-04-12 canvis menors esquematic
    [Alimentacio.kicad_sch, Grup3_Tarda_Projecte_Netejaparabrises.kicad_sch, Microcontrolador.kicad_sch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]
2023-04-12 canvis reles
    [Alimentacio.kicad_sch, Microcontrolador.kicad_sch, Potencia.kicad_sch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]
2023-04-13 Layout 3
    [1393280-6.step, Alimentacio.kicad_sch, Grup3_Tarda_Projecte_Netejaparabrises.kicad_pcb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]
2023-04-17 canvis divisor sensor de pluja, node vbat protegit, connector de motors, README
    [Alimentacio.kicad_sch, Grup3_Tarda_Projecte_Netejaparabrises.kicad_pcb, Potencia.kicad_sch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]
2023-04-18 plans de massa i alimentacio layout
    [Alimentacio.kicad_sch, Grup3_Tarda_Projecte_Netejaparabrises.kicad_pcb]
2023-04-19 routing v1 sense acabar
    [Alimentacio.kicad_sch, Grup3_Tarda_Projecte_Netejaparabrises.dsn, Grup3_Tarda_Projecte_Netejaparabrises.kicad_pcb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]
2023-04-20 canvis menors layout
    [Alimentacio.kicad_sch, Grup3_Tarda_Projecte_Netejaparabrises.kicad_pcb, Grup3_Tarda_Projecte_Netejaparabrises.kicad_sch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]
2023-04-25 placing rooting
    [Alimentacio.kicad_sch, Grup3_Tarda_Projecte_Netejaparabrises.kicad_pcb, Microcontrolador.kicad_sch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]
2023-04-25 redefinicio copper pours, rerouting, final de carrera i teardrops
    [Grup3_Tarda_Projecte_Netejaparabrises.kicad_pcb, Microcontrolador.kicad_sch, Sensor_Pluja.kicad_sch]
2023-04-26 afegits els finals de carrera dels motors
    [Grup3_Tarda_Projecte_Netejaparabrises.kicad_pcb, Microcontrolador.kicad_sch]
2023-04-26 canvi de posicio de ferrites i connectors reset debug
    [Grup3_Tarda_Projecte_Netejaparabrises.kicad_pcb]
2023-04-26 Fitxer BOM
    [Alimentacio.kicad_sch, Grup3_Tarda_Projecte_Netejaparabrises.csv, Grup3_Tarda_Projecte_Netejaparabrises.kicad_pcb]
2023-04-26 canvis diagrama de blocs i README
2023-04-26 fitxer BOM amb footprints i mes
    [Grup3_Tarda_Projecte_Netejaparabrises.csv]
2023-04-26 canvi de fitxer BOM
    [Grup3_Tarda_Projecte_Netejaparabrises.csv]
2023-04-27 modificacions BOM
    [Grup3_Tarda_Projecte_Netejaparabrises.csv]
2023-04-27 gerbers i 3d
    [Grup3_Tarda_Projecte_Netejaparabrises.kicad_pcb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]
2023-04-27 commit final
    [Grup3_Tarda_Projecte_Netejaparabrises-B_Cu.gbr, Grup3_Tarda_Projecte_Netejaparabrises-B_Mask.gbr, Grup3_Tarda_Projecte_Netejaparabrises-B_Paste.gbr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]
